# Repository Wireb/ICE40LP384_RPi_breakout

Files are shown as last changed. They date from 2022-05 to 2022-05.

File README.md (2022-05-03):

# ICE40LP384 to Raspberry Pi breakout
This repo is a collection of files related to my failed FPGA based quad scale interface board. 

The board worked but there was insufficient FPGA space for project. 

The FPGA board works and I was able to load simple projects from the Pi to the FPGA and communicate with it over SPI

## iCEcube2
The FPGA code was built with release 220.12.27943 using the free license key. See PiDRO vhdl for the source. Note this code is different than the version included in the python directory. I was not able to find the source to that version. 

## KiCad
This is a KiCad 6.x project. 

## Documentation

primary script is in the Python directory and called PiDRO.py. This loads the FPGA bitmap image to the card then communicates via the SPI bus. (The FPGA uses the SPI bus to load it's data then released the lines to internal IO control.) Note this tool uses "pigpiod" to control the Raspberry Pi's GPIOs and SPI interfaces. Make sure pigpiod is running before trying to use this script. 

There is a second script that uses GPIOzero and the SPI IO device. It worked but moved to pigpiod since it could do both SPI and GPIO in one tool. 

Either case the file you want after building the bitmap can be found in \iCEcube2\PiDRO_Implmnt\sbt\outputs\bitmap\PiDRO_bitmap.bin. The documentation was confusing and made it sound like a second tool was needed to generate the file. That is not the case just use iCEcube2 to generate the bitmap as part of the P&R steps then grab it from that directory. 

Copyright (c) 2022 Peter Shabino

Permission is hereby granted, free of charge, to any person obtaining a copy of this hardware, software, and associated documentation files 
(the "Product"), to deal in the Product without restriction, including without limitation the rights to use, copy, modify, merge, publish, 
distribute, sublicense, and/or sell copies of the Product, and to permit persons to whom the Product is furnished to do so, subject to the 
following conditions:

The above copyright notice and this permission notice shall be included in all copies or substantial portions of the Product.

THE PRODUCT IS PROVIDED "AS IS", WITHOUT WARRANTY OF ANY KIND, EXPRESS OR IMPLIED, INCLUDING BUT NOT LIMITED TO THE WARRANTIES OF 
MERCHANTABILITY, FITNESS FOR A PARTICULAR PURPOSE AND NONINFRINGEMENT. IN NO EVENT SHALL THE AUTHORS OR COPYRIGHT HOLDERS BE LIABLE 
FOR ANY CLAIM, DAMAGES OR OTHER LIABILITY, WHETHER IN AN ACTION OF CONTRACT, TORT OR OTHERWISE, ARISING FROM, OUT OF OR IN CONNECTION 
WITH THE PRODUCT OR THE USE OR OTHER DEALINGS IN THE PRODUCT.

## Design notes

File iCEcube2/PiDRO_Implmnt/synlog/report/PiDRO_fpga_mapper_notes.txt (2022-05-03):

@N: MF248 |Running in 64-bit mode.
@N: MF666 |Clock conversion enabled. (Command "set_option -fix_gated_and_generated_clocks 1" in the project file.)
@N: MO111 :|Tristate driver tri0_inst (in view: work.PiDRO(struct)) on net counts[119] (in view: work.PiDRO(struct)) has its enable tied to GND.
@N: MO111 :|Tristate driver tri1_inst (in view: work.PiDRO(struct)) on net counts[118] (in view: work.PiDRO(struct)) has its enable tied to GND.
@N: MO111 :|Tristate driver tri2_inst (in view: work.PiDRO(struct)) on net counts[117] (in view: work.PiDRO(struct)) has its enable tied to GND.
@N: MO111 :|Tristate driver tri3_inst (in view: work.PiDRO(struct)) on net counts[116] (in view: work.PiDRO(struct)) has its enable tied to GND.
@N: MO111 :|Tristate driver tri4_inst (in view: work.PiDRO(struct)) on net counts[115] (in view: work.PiDRO(struct)) has its enable tied to GND.
@N: MO111 :|Tristate driver tri5_inst (in view: work.PiDRO(struct)) on net counts[114] (in view: work.PiDRO(struct)) has its enable tied to GND.
@N: MO111 :|Tristate driver tri6_inst (in view: work.PiDRO(struct)) on net counts[113] (in view: work.PiDRO(struct)) has its enable tied to GND.
@N: MO111 :|Tristate driver tri7_inst (in view: work.PiDRO(struct)) on net counts[112] (in view: work.PiDRO(struct)) has its enable tied to GND.
@N: MO111 :|Tristate driver tri8_inst (in view: work.PiDRO(struct)) on net counts[111] (in view: work.PiDRO(struct)) has its enable tied to GND.
@N: MO111 :|Tristate driver tri9_inst (in view: work.PiDRO(struct)) on net counts[110] (in view: work.PiDRO(struct)) has its enable tied to GND.
@N: MT206 |Auto Constrain mode is enabled
@N: FX271 :"d:\cam_offload_cache\icecube2_projects\pidro\pidro\pidro.vhdl":173:1:173:3|Replicating instance SPI.shift_reg_rst (in view: work.PiDRO(struct)) with 120 loads 3 times to improve timing.
@N: FX271 :"d:\cam_offload_cache\icecube2_projects\pidro\pidro\pidro.vhdl":173:1:173:3|Replicating instance SPI.shift_reg_rst (in view: work.PiDRO(struct)) with 30 loads 2 times to improve timing.
@N: FX271 :"d:\cam_offload_cache\icecube2_projects\pidro\pidro\pidro.vhdl":173:1:173:3|Replicating instance SPI.shift_reg_rst_fast (in view: work.PiDRO(struct)) with 30 loads 2 times to improve timing.
@N: FX271 :"d:\cam_offload_cache\icecube2_projects\pidro\pidro\pidro.vhdl":173:1:173:3|Replicating instance SPI.shift_reg_rst_rep1 (in view: work.PiDRO(struct)) with 30 loads 2 times to improve timing.
@N: FX271 :"d:\cam_offload_cache\icecube2_projects\pidro\pidro\pidro.vhdl":173:1:173:3|Replicating instance SPI.shift_reg_rst_rep2 (in view: work.PiDRO(struct)) with 30 loads 2 times to improve timing.
@N: FX1016 :"d:\cam_offload_cache\icecube2_projects\pidro\pidro\pidro.vhdl":97:3:97:9|SB_GB_IO inserted on the port SPI_SCK.
@N: BW103 |The default time unit for the Synopsys Constraint File (SDC or FDC) is 1ns.
@N: BW107 |Synopsys Constraint File capacitance units using default value of 1pF 
@N: FX1056 |Writing EDF file: D:\cam_offload_cache\iCEcube2_projects\PiDRO\PiDRO\PiDRO_Implmnt\PiDRO.edf
@N: MT320 |This timing report is an estimate of place and route data. For final timing results, use the FPGA vendor place and route report.
@N: MT322 |Clock constraints include only register-to-register paths associated with each individual clock.

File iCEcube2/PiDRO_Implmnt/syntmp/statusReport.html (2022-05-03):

Project Settings
Project Name | PiDRO_syn | Implementation Name | PiDRO_Implmnt
Top Module | [auto] | Pipelining | 1
Retiming | 0 | Resource Sharing | 1
Fanout Guide | 10000 | Disable I/O Insertion | 0
Disable Sequential Optimizations | 0 | Clock Conversion | 1

Run Status
Job Name | Status | | | | CPU Time | Real Time | Memory | Date/Time
(compiler) | Complete | 24 | 3 | 0 | - | 00m:00s | - | 5/3/2022 6:25:15 PM
(premap) | Complete | 13 | 121 | 0 | 0m:00s | 0m:00s | 134MB | 5/3/2022 6:25:17 PM
(fpga_mapper) | Complete | 24 | 131 | 0 | 0m:00s | 0m:00s | 134MB | 5/3/2022 6:25:18 PM
Multi-srs Generator | Complete | | | | | | | 5/3/2022 6:25:16 PM

Area Summary
PADS | 20 | FLOPS | 133
RAMS (v_ram) | 0 | CARRYS | 0
LUTS (total_luts) | 121

Timing Summary
Clock Name | Req Freq | Est Freq | Slack
PiDRO|SPI_SCK | 249.3 MHz | 211.9 MHz | -0.708

Optimizations Summary
Combined Clock Conversion | 1 / 0

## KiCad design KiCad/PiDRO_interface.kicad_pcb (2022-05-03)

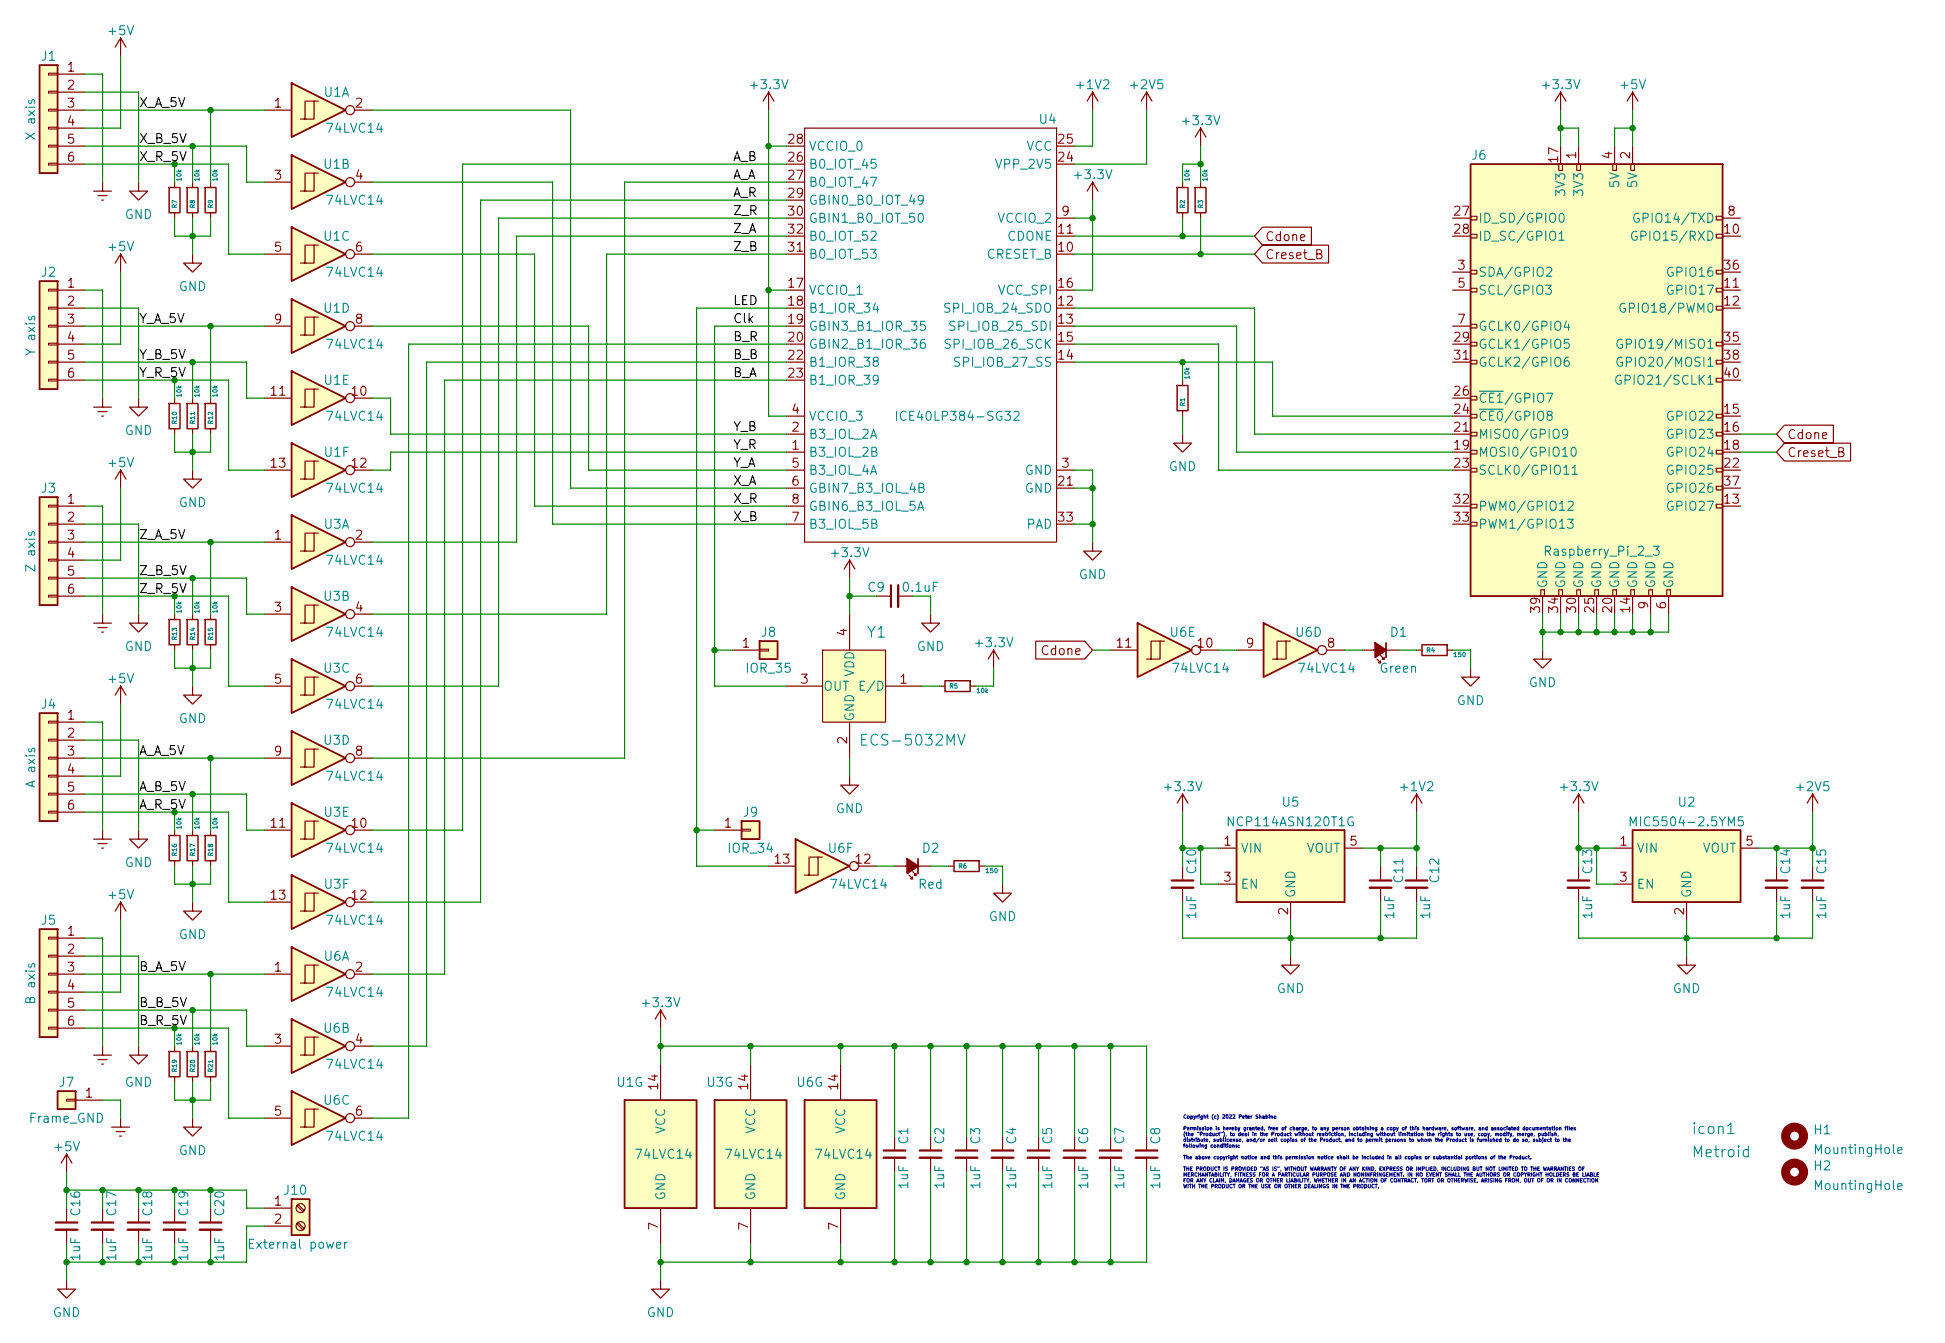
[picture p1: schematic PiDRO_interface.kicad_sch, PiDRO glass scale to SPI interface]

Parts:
C1, C2, C3, C4, C5, C6, C7, C8, C10, C11, C12, C13, C14, C15, C16, C17, C18, C19, C20: 1uF; C_0805_2012Metric
C9: 0.1uF; C_0603_1608Metric
D1: Green; LED_0805_2012Metric
D2: Red; LED_0805_2012Metric
H1, H2: MountingHole; MountingHole_2.7mm
J1: X axis; PinHeader_2x03_P2.54mm_Vertical
J2: Y axis; PinHeader_2x03_P2.54mm_Vertical
J3: Z axis; PinHeader_2x03_P2.54mm_Vertical
J4: A axis; PinHeader_2x03_P2.54mm_Vertical
J5: B axis; PinHeader_2x03_P2.54mm_Vertical
J6: Raspberry_Pi_2_3; Raspberry_Pi_Zero_Socketed_THT_FaceDown_MountingHoles
J7: Frame_GND; PinHeader_1x01_P2.54mm_Vertical
J8: IOR_35; PinHeader_1x01_P2.54mm_Vertical
J9: IOR_34; PinHeader_1x01_P2.54mm_Vertical
J10: External power; OSTTE020104
R1, R2, R3, R5, R7, R8, R9, R10, R11, R12, R13, R14, R15, R16, R17, R18, R19, R20, R21: 10k; R_0603_1608Metric
R4, R6: 150; R_0603_1608Metric
U1, U3, U6: 74LVC14; SO-14_5.3x10.2mm_P1.27mm
U2: MIC5504-2.5YM5; SOT-23-5
U4: ICE40LP384-SG32; TQFN-32-1EP_5x5mm_P0.5mm_EP2.1x2.1mm
U5: NCP114ASN120T1G; TSOP-5_1.65x3.05mm_P0.95mm
Y1: ECS-5032MV; Oscillator_XLH736022.579200I; MPN XLH736022.579200I; Digi-Key_PN 631-1277-ND
icon1: Metroid; metroid

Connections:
+1V2: C11.1, C12.1, U4.25 (VCC), U5.5 (VOUT)
+2V5: C14.1, C15.1, U2.5 (VOUT), U4.24 (VPP_2V5)
+3V3: C1.1, C2.1, C3.1, C4.1, C5.1, C6.1, C7.1, C8.1, C9.1, C10.1, C13.1, J6.1 (3V3), J6.17 (3V3), R2.1, R3.1, R5.1, U1.14 (VCC), U2.1 (VIN), U2.3 (EN), U3.14 (VCC), U4.4 (VCCIO_3), U4.9 (VCCIO_2), U4.16 (VCC_SPI), U4.17 (VCCIO_1), U4.28 (VCCIO_0), U5.1 (VIN), U5.3 (EN), U6.14 (VCC), Y1.4 (VDD)
+5V: C16.1, C17.1, C18.1, C19.1, C20.1, J1.4, J2.4, J3.4, J4.4, J5.4, J6.2 (5V), J6.4 (5V), J10.1
/A_A: U3.8, U4.27 (B0_IOT_47)
/A_B: U3.10, U4.26 (B0_IOT_45)
/A_R: U3.12, U4.29 (GBIN0_B0_IOT_49)
/B_A: U4.23 (B1_IOR_39), U6.2
/B_B: U4.22 (B1_IOR_38), U6.4
/B_R: U4.20 (GBIN2_B1_IOR_36), U6.6
/Clk: J8.1, U4.19 (GBIN3_B1_IOR_35), Y1.3 (OUT)
/LED: J9.1, U4.18 (B1_IOR_34), U6.13
/X_A: U1.2, U4.6 (GBIN7_B3_IOL_4B)
/X_B: U1.4, U4.7 (B3_IOL_5B)
/X_R: U1.6, U4.8 (GBIN6_B3_IOL_5A)
/Y_A: U1.8, U4.5 (B3_IOL_4A)
/Y_B: U1.10, U4.2 (B3_IOL_2A)
/Y_R: U1.12, U4.1 (B3_IOL_2B)
/Z_A: U3.2, U4.32 (B0_IOT_52)
/Z_B: U3.4, U4.31 (B0_IOT_53)
/Z_R: U3.6, U4.30 (GBIN1_B0_IOT_50)
Cdone: J6.16 (GPIO23), R2.2, U4.11 (CDONE), U6.11
Creset_B: J6.18 (GPIO24), R3.2, U4.10 (CRESET_B)
Earth: J1.1, J2.1, J3.1, J4.1, J5.1, J7.1
unnamed: D1.1 (K), R4.2
unnamed: D1.2 (A), U6.8
unnamed: D2.1 (K), R6.2
unnamed: D2.2 (A), U6.12
unnamed: J6.19 (MOSI0/GPIO10), U4.13 (SPI_IOB_25_SDI)
unnamed: J6.21 (MISO0/GPIO9), U4.12 (SPI_IOB_24_SDO)
unnamed: J6.23 (SCLK0/GPIO11), U4.15 (SPI_IOB_26_SCK)
unnamed: J6.24 (~CE0/GPIO8), R1.1, U4.14 (SPI_IOB_27_SS)
unnamed: R5.2, Y1.1 (E/D)
unnamed: U6.9, U6.10

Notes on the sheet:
Copyright (c) 2022 Peter Shabino Permission is hereby granted, free of charge, to any person obtaining a copy of this hardware, software, and associated documentation files (the "Product"), to deal in the Product without restriction, including without limitation the rights to use, copy, modify, mer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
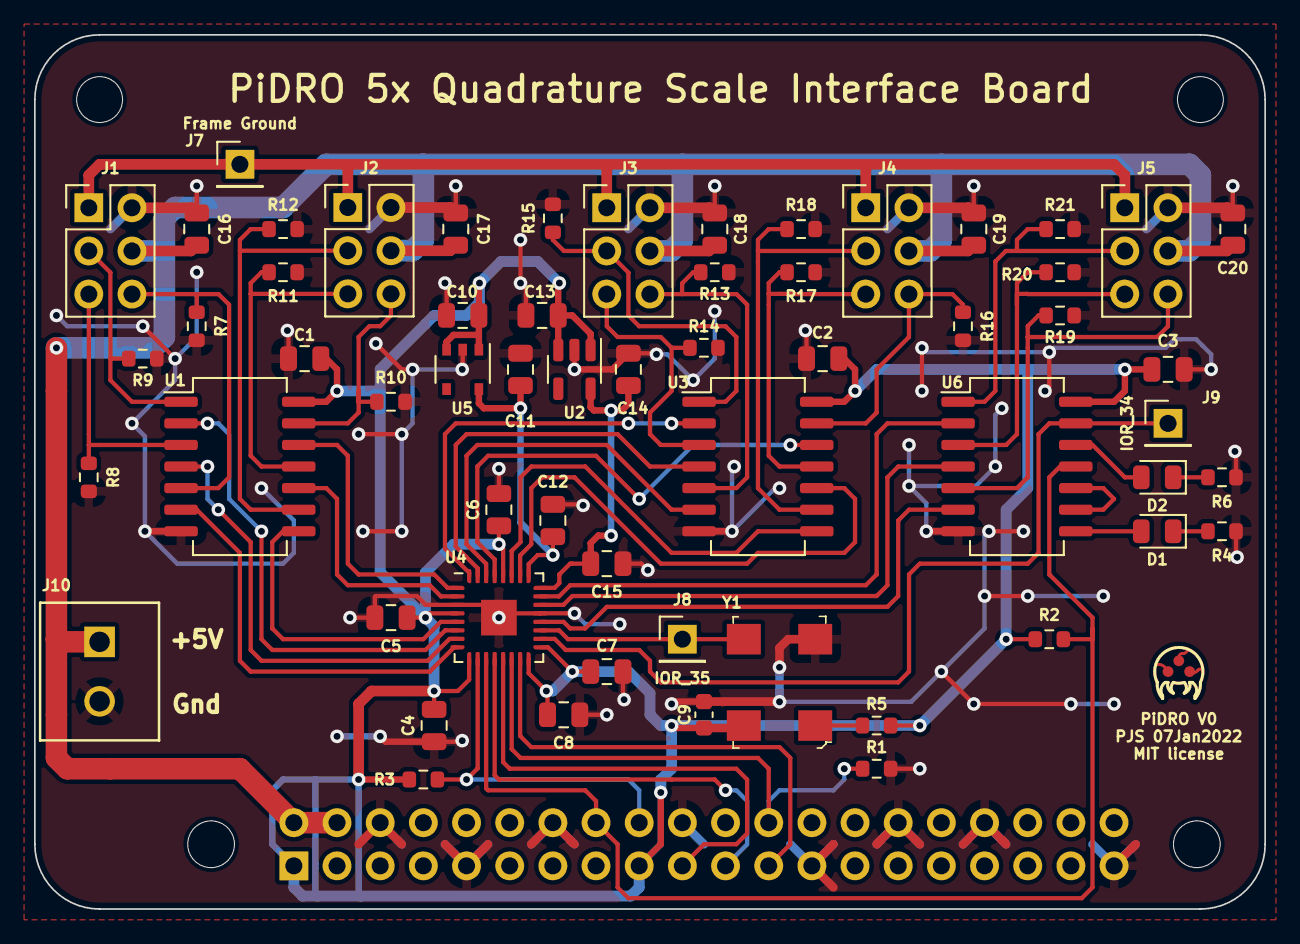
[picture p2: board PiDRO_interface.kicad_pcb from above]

Board: 2 copper layers, 72.4 x 51.4 mm, 63 parts (1 on the bottom side), 50 nets.

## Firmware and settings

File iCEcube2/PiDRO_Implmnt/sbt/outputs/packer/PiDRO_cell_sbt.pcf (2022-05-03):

ble_pack SPI.shift_reg_106_LC_2_1_1 { SPI.shift_reg_RNO[106], SPI.shift_reg[106] }
ble_pack SPI.shift_reg_105_LC_2_1_4 { SPI.shift_reg_RNO[105], SPI.shift_reg[105] }
ble_pack SPI.shift_reg_107_LC_2_1_5 { SPI.shift_reg_RNO[107], SPI.shift_reg[107] }
ble_pack SPI.shift_reg_108_LC_2_1_6 { SPI.shift_reg_RNO[108], SPI.shift_reg[108] }
ble_pack SPI.shift_reg_0_LC_2_1_7 { SPI.shift_reg_0_THRU_LUT4_0, SPI.shift_reg[0] }
clb_pack LT_2_1 { SPI.shift_reg_106_LC_2_1_1, SPI.shift_reg_105_LC_2_1_4, SPI.shift_reg_107_LC_2_1_5, SPI.shift_reg_108_LC_2_1_6, SPI.shift_reg_0_LC_2_1_7 }
set_location LT_2_1 2 1
ble_pack SPI.shift_reg_6_LC_2_2_0 { SPI.shift_reg_RNO[6], SPI.shift_reg[6] }
ble_pack SPI.shift_reg_2_LC_2_2_1 { SPI.shift_reg_RNO[2], SPI.shift_reg[2] }
ble_pack SPI.shift_reg_3_LC_2_2_2 { SPI.shift_reg_RNO[3], SPI.shift_reg[3] }
ble_pack SPI.shift_reg_4_LC_2_2_3 { SPI.shift_reg_RNO[4], SPI.shift_reg[4] }
ble_pack SPI.shift_reg_5_LC_2_2_4 { SPI.shift_reg_RNO[5], SPI.shift_reg[5] }
ble_pack SPI.shift_reg_1_LC_2_2_5 { SPI.shift_reg_RNO[1], SPI.shift_reg[1] }
ble_pack SPI.shift_reg_7_LC_2_2_6 { SPI.shift_reg_RNO[7], SPI.shift_reg[7] }
ble_pack SPI.shift_reg_8_LC_2_2_7 { SPI.shift_reg_RNO[8], SPI.shift_reg[8] }
clb_pack LT_2_2 { SPI.shift_reg_6_LC_2_2_0, SPI.shift_reg_2_LC_2_2_1, SPI.shift_reg_3_LC_2_2_2, SPI.shift_reg_4_LC_2_2_3, SPI.shift_reg_5_LC_2_2_4, SPI.shift_reg_1_LC_2_2_5, SPI.shift_reg_7_LC_2_2_6, SPI.shift_reg_8_LC_2_2_7 }
set_location LT_2_2 2 2
ble_pack SPI.shift_reg_10_LC_2_3_0 { SPI.shift_reg_RNO[10], SPI.shift_reg[10] }
ble_pack SPI.shift_reg_9_LC_2_3_1 { SPI.shift_reg_RNO[9], SPI.shift_reg[9] }
ble_pack SPI.shift_reg_11_LC_2_3_2 { SPI.shift_reg_RNO[11], SPI.shift_reg[11] }
ble_pack SPI.shift_reg_12_LC_2_3_3 { SPI.shift_reg_RNO[12], SPI.shift_reg[12] }
ble_pack SPI.shift_reg_13_LC_2_3_4 { SPI.shift_reg_RNO[13], SPI.shift_reg[13] }
ble_pack SPI.shift_reg_14_LC_2_3_5 { SPI.shift_reg_RNO[14], SPI.shift_reg[14] }
ble_pack SPI.shift_reg_15_LC_2_3_6 { SPI.shift_reg_RNO[15], SPI.shift_reg[15] }
ble_pack SPI.shift_reg_16_LC_2_3_7 { SPI.shift_reg_RNO[16], SPI.shift_reg[16] }
clb_pack LT_2_3 { SPI.shift_reg_10_LC_2_3_0, SPI.shift_reg_9_LC_2_3_1, SPI.shift_reg_11_LC_2_3_2, SPI.shift_reg_12_LC_2_3_3, SPI.shift_reg_13_LC_2_3_4, SPI.shift_reg_14_LC_2_3_5, SPI.shift_reg_15_LC_2_3_6, SPI.shift_reg_16_LC_2_3_7 }
set_location LT_2_3 2 3
ble_pack SPI.shift_reg_rst_fast_rep1_LC_3_1_4 { SPI.shift_reg_rst_fast_rep1_THRU_LUT4_0, SPI.shift_reg_rst_fast_rep1 }
clb_pack LT_3_1 { SPI.shift_reg_rst_fast_rep1_LC_3_1_4 }
set_location LT_3_1 3 1
ble_pack SPI.shift_reg_109_LC_3_2_0 { SPI.shift_reg_RNO[109], SPI.shift_reg[109] }
ble_pack SPI.shift_reg_110_LC_3_2_1 { SPI.shift_reg_RNO[110], SPI.shift_reg[110] }
ble_pack SPI.shift_reg_111_LC_3_2_2 { SPI.shift_reg_RNO[111], SPI.shift_reg[111] }
ble_pack SPI.shift_reg_112_LC_3_2_3 { SPI.shift_reg_RNO[112], SPI.shift_reg[112] }
ble_pack SPI.shift_reg_113_LC_3_2_4 { SPI.shift_reg_RNO[113], SPI.shift_reg[113] }
ble_pack SPI.shift_reg_114_LC_3_2_5 { SPI.shift_reg_RNO[114], SPI.shift_reg[114] }
ble_pack SPI.shift_reg_115_LC_3_2_6 { SPI.shift_reg_RNO[115], SPI.shift_reg[115] }
ble_pack SPI.shift_reg_116_LC_3_2_7 { SPI.shift_reg_RNO[116], SPI.shift_reg[116] }
clb_pack LT_3_2 { SPI.shift_reg_109_LC_3_2_0, SPI.shift_reg_110_LC_3_2_1, SPI.shift_reg_111_LC_3_2_2, SPI.shift_reg_112_LC_3_2_3, SPI.shift_reg_113_LC_3_2_4, SPI.shift_reg_114_LC_3_2_5, SPI.shift_reg_115_LC_3_2_6, SPI.shift_reg_116_LC_3_2_7 }
set_location LT_3_2 3 2
ble_pack SPI.shift_reg_rst_LC_3_3_0 { SPI.shift_reg_rst_THRU_LUT4_0, SPI.shift_reg_rst }
ble_pack SPI.shift_reg_rst_fast_0_LC_3_3_2 { SPI.shift_reg_rst_fast_0_THRU_LUT4_0, SPI.shift_reg_rst_fast_0 }
ble_pack SPI.shift_reg_rst_fast_fast_LC_3_3_3 { SPI.shift_reg_rst_fast_fast_THRU_LUT4_0, SPI.shift_reg_rst_fast_fast }
ble_pack SPI.shift_reg_rst_rep1_LC_3_3_5 { SPI.shift_reg_rst_rep1_THRU_LUT4_0, SPI.shift_reg_rst_rep1 }
ble_pack SPI.shift_reg_rst_rep1_0_LC_3_3_6 { SPI.shift_reg_rst_rep1_0_THRU_LUT4_0, SPI.shift_reg_rst_rep1_0 }
ble_pack SPI.shift_reg_rst_rep1_fast_LC_3_3_7 { SPI.shift_reg_rst_rep1_fast_THRU_LUT4_0, SPI.shift_reg_rst_rep1_fast }
clb_pack LT_3_3 { SPI.shift_reg_rst_LC_3_3_0, SPI.shift_reg_rst_fast_0_LC_3_3_2, SPI.shift_reg_rst_fast_fast_LC_3_3_3, SPI.shift_reg_rst_rep1_LC_3_3_5, SPI.shift_reg_rst_rep1_0_LC_3_3_6, SPI.shift_reg_rst_rep1_fast_LC_3_3_7 }
set_location LT_3_3 3 3
ble_pack SPI.shift_reg_22_LC_3_4_0 { SPI.shift_reg_RNO[22], SPI.shift_reg[22] }
ble_pack SPI.shift_reg_23_LC_3_4_1 { SPI.shift_reg_RNO[23], SPI.shift_reg[23] }
ble_pack SPI.shift_reg_24_LC_3_4_2 { SPI.shift_reg_RNO[24], SPI.shift_reg[24] }
ble_pack SPI.shift_reg_25_LC_3_4_3 { SPI.shift_reg_RNO[25], SPI.shift_reg[25] }
ble_pack SPI.shift_reg_26_LC_3_4_4 { SPI.shift_reg_RNO[26], SPI.shift_reg[26] }
ble_pack SPI.shift_reg_27_LC_3_4_5 { SPI.shift_reg_RNO[27], SPI.shift_reg[27] }
ble_pack SPI.shift_reg_28_LC_3_4_6 { SPI.shift_reg_RNO[28], SPI.shift_reg[28] }
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

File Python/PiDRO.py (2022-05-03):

# IO map
# GPIO8 - SPI SS - pull down
# GPIO9 - SPI MISO0
# GPIO10 - SPI MOSI0
# GPIO11 - SCLK0
# GPIO23 - Cdone - pull up - green LED when high
# GPIO24 - Creset_B - pull up 

# start pigpio with "sudo pigpiod"
# automatic startup "sudo systemctl enable pigpiod"
# https://scispec.dev/2020/04/04/blink-led-with-python-and-pigpio-library-2/
# pigpio documentation https://abyz.me.uk/rpi/pigpio/python.html
# https://www.dummies.com/article/technology/computers/hardware/raspberry-pi/raspberry-pi-gpio-pin-alternate-functions-143761



import time
import sys
import pigpio 

###############################################
bitmap_file = "./PiDRO_bitmap.bin"
# pins
SPI_SS = 8
SPI_MISO = 9
SPI_MOSI = 10
SPI_CLK = 11
Cdone = 23
Creset_B = 24



###############################################
# open GPIO pins
pi = pigpio.pi()

# setup GPIOs
pi.set_mode(SPI_SS, pigpio.OUTPUT)
pi.set_mode(Cdone, pigpio.INPUT)
pi.set_mode(Creset_B, pigpio.OUTPUT)

# setup SPI
# SPI engine 0 is on ALT0 pins
#pi.set_mode(SPI_SS, pigpio.ALT0)  # set to manual control for now. 
pi.set_mode(SPI_MISO, pigpio.ALT0)
pi.set_mode(SPI_MOSI, pigpio.ALT0)
pi.set_mode(SPI_CLK, pigpio.ALT0)
spi = pi.spi_open(spi_channel=0, baud=2000000, spi_flags=0x000003)
# SPI flags 
#21 20 19 18 17 16  |  15 14 13 12 11 10  9  8  |  7  6  5  4  3  2  1  0
# b  b  b  b  b  b  |  R  T  n  n  n  n   W  A  |  u2 u1 u0 p2 p1 p0  m  m
# b = word size set to 0 for 8 bit (default). Aux SPI only
# R = 1 LSB received first, 0 = MSB received first (default) Aux SPI only
# T = 1 LSB sent first, 0 = MSB sent first (default) Aux SPI only
# n = number of bytes to write before switching to read. Ingored if W not set
# W = 1 3 wire mode, 0 = 4 wire mode (default). Main SPI only
# A = 1 for Aux SPI engine, 0 = main engine (default)
# ux = 0 if pin is reserved for SPI (default) 
# px = 0 for active low, 1 for active high (does this even work still due to kernel change?)
# m = SPI mode bits POL(clk), PHA(data latch) note modes 1 and 3 do not seem to work on Aux SPI engine.

#init FPGA
print("reset FPGA")
# drive Creset_B low to reset FPGA
pi.write(Creset_B, False)
# drive SPI_SS low 
pi.write(SPI_SS, False)
# hold reset for at least 200nS
time.sleep(1/1000000)  # 1uS

# check if FPGA is reset
if(pi.read(Cdone) == 1):
    print("Error occurred Cdone is active. Exiting")
    sys.exit(-1)

# release reset
pi.write(Creset_B, True)
# allow at least 1200us for the iCE40 to clear internal memory
time.sleep(2000/1000000)  # 2000uS

print("Load FPGA image")
# drive SPI_SS high for 8 SPI clock cycles
pi.write(SPI_SS, True)
pi.spi_write(spi, [0x00])
# read in bitmap
print("  file "+bitmap_file)
file = open(bitmap_file, mode='rb')
bitmap_data = file.read()
file.close()
print("  Read "+str(len(bitmap_data))+" bitmap bytes")
# drive SS active (low)
pi.write(SPI_SS, False)
# send full bitmap
pi.spi_write(spi, bitmap_data)
# drive SS inactive (high)
pi.write(SPI_SS, True)

# send 100 more bytes
for x in range(100):
    pi.spi_write(spi, [0x00])


if(pi.read(Cdone) == 0):
    print("Error occurred Cdone is inactive. Exiting")
    sys.exit(-1)


# drive SS active (low)
pi.write(SPI_SS, False)
# read 15 bytes
(b, d) = pi.spi_xfer(spi, [0xB0, 0xB0, 0xC0, 0xED, 0, 0, 0, 0, 0, 0, 0, 0, 0, 0, 0])
# drive SS inactive (high)
pi.write(SPI_SS, True)

print("xfer 2 got ",b," bytes")
print(d)

while(1):
    # drive SS active (low)
    pi.write(SPI_SS, False)
    # read 15 bytes
    (b, d) = pi.spi_xfer(spi, [1, 2, 3, 4, 0, 0, 0, 0, 0, 0, 0, 0, 0xFF, 0xFF, 0xFF])
    # drive SS inactive (high)
    pi.write(SPI_SS, True)

    print("got ",b," bytes")
    print(d)
    
    time.sleep(1)

print("script done")
sys.exit()

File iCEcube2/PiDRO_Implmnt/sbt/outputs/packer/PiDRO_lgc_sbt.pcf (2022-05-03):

set_location CONSTANT_ONE_LUT4 5 6 7 #SB_LUT4
set_location SPI.shift_reg_rst_rep2_rep1_THRU_LUT4_0 4 6 3 #SB_LUT4
set_location SPI.shift_reg_rst_rep2_fast_THRU_LUT4_0 4 6 2 #SB_LUT4
set_location SPI.shift_reg_rst_rep2_THRU_LUT4_0 4 6 1 #SB_LUT4
set_location SPI.shift_reg_rst_rep1_rep1_THRU_LUT4_0 4 6 0 #SB_LUT4
set_location SPI.shift_reg_rst_rep1_fast_THRU_LUT4_0 3 3 7 #SB_LUT4
set_location SPI.shift_reg_rst_rep1_0_THRU_LUT4_0 3 3 6 #SB_LUT4
set_location SPI.shift_reg_rst_rep1_THRU_LUT4_0 3 3 5 #SB_LUT4
set_location SPI.shift_reg_rst_fast_rep1_THRU_LUT4_0 3 1 4 #SB_LUT4
set_location SPI.shift_reg_rst_fast_fast_THRU_LUT4_0 3 3 3 #SB_LUT4
set_location SPI.shift_reg_rst_fast_0_THRU_LUT4_0 3 3 2 #SB_LUT4
set_location SPI.shift_reg_rst_fast_THRU_LUT4_0 5 2 6 #SB_LUT4
set_location SPI.shift_reg_rst_THRU_LUT4_0 3 3 0 #SB_LUT4
set_location SPI.shift_reg_0_THRU_LUT4_0 2 1 7 #SB_LUT4
set_location SPI.shift_reg_RNO[44] 4 7 6 #SB_LUT4
set_location SPI.shift_reg_RNO[23] 3 4 1 #SB_LUT4
set_location SPI.shift_reg_RNO[96] 5 1 4 #SB_LUT4
set_location SPI.shift_reg_RNO[5] 2 2 4 #SB_LUT4
set_location SPI.shift_reg_rst_rep2_rep1 4 6 3 #SB_DFFNR
set_location SPI.shift_reg_rst_fast 5 2 6 #SB_DFFNR
set_location SPI.shift_reg_RNO[103] 4 1 4 #SB_LUT4
set_location SPI.shift_reg[90] 4 2 4 #SB_DFFN
set_location SPI.shift_reg[26] 3 4 4 #SB_DFFN
set_location SPI.shift_reg[113] 3 2 4 #SB_DFFN
set_location SPI.shift_reg[0] 2 1 7 #SB_DFFN
set_location SPI.shift_reg_RNO[41] 3 7 3 #SB_LUT4
set_location SPI.shift_reg_RNO[28] 3 4 6 #SB_LUT4
set_location SPI.shift_reg[45] 4 7 7 #SB_DFFN
set_location SPI.shift_reg_rst_fast_0 3 3 2 #SB_DFFNR
set_location SPI.shift_reg_RNO[19] 4 3 5 #SB_LUT4
set_location SPI.shift_reg[67] 4 3 7 #SB_DFFN
set_location SPI.shift_reg_RNO[59] 3 5 5 #SB_LUT4
set_location SPI.shift_reg_RNO[112] 3 2 3 #SB_LUT4
set_location SPI.shift_reg_RNO[106] 2 1 1 #SB_LUT4
set_location SPI.shift_reg[5] 2 2 4 #SB_DFFN
set_location SPI.shift_reg[118] 4 2 1 #SB_DFFN
set_location SPI.shift_reg_RNO[80] 4 5 7 #SB_LUT4
set_location SPI.shift_reg_RNO[8] 2 2 7 #SB_LUT4
set_location SPI.shift_reg_RNO[67] 4 3 7 #SB_LUT4
set_location SPI.shift_reg_RNO[32] 3 6 2 #SB_LUT4
set_location SPI.shift_reg[42] 3 7 4 #SB_DFFN
set_location SPI.shift_reg_RNO[98] 5 1 2 #SB_LUT4
set_location SPI.shift_reg_RNO[14] 2 3 5 #SB_LUT4
set_location SPI.shift_reg[82] 4 5 4 #SB_DFFN
set_location SPI.shift_reg[60] 3 5 1 #SB_DFFN
set_location SPI.shift_reg[37] 3 6 7 #SB_DFFN
set_location SPI.shift_reg[18] 4 3 4 #SB_DFFN
set_location SPI.shift_reg[102] 4 1 3 #SB_DFFN
set_location SPI.shift_reg_RNO[85] 4 4 2 #SB_LUT4
set_location SPI.shift_reg_RNO[35] 3 6 0 #SB_LUT4
set_location SPI.shift_reg[71] 4 5 0 #SB_DFFN
set_location SPI.SDO_RNO 5 3 6 #SB_LUT4
set_location SPI.shift_reg_RNO[13] 2 3 4 #SB_LUT4
set_location SPI.shift_reg[87] 4 2 5 #SB_DFFN
set_location SPI.shift_reg[32] 3 6 2 #SB_DFFN
set_location SPI.shift_reg[13] 2 3 4 #SB_DFFN
set_location SPI.shift_reg_RNO[76] 5 5 6 #SB_LUT4
set_location SPI.shift_reg_RNO[53] 3 7 7 #SB_LUT4
set_location SPI.shift_reg_RNO[20] 4 3 6 #SB_LUT4
set_location SPI.shift_reg_RNO[118] 4 2 1 #SB_LUT4
set_location SPI.shift_reg[53] 3 7 7 #SB_DFFN
set_location SPI.shift_reg[105] 2 1 4 #SB_DFFN
set_location SPI.shift_reg_RNO[95] 5 1 6 #SB_LUT4
set_location SPI.shift_reg_RNO[38] 3 7 0 #SB_LUT4
set_location SPI.shift_reg_RNO[2] 2 2 1 #SB_LUT4
set_location SPI.shift_reg[74] 5 5 4 #SB_DFFN
set_location SPI.shift_reg[93] 4 1 7 #SB_DFFN
set_location SPI.shift_reg[39] 3 7 1 #SB_DFFN
set_location SPI.shift_reg[23] 3 4 1 #SB_DFFN
set_location SPI.shift_reg[16] 2 3 7 #SB_DFFN
set_location SPI.shift_reg[110] 3 2 1 #SB_DFFN
set_location SPI.shift_reg_RNO[71] 4 5 0 #SB_LUT4
set_location SPI.shift_reg_RNO[56] 3 5 0 #SB_LUT4
set_location SPI.shift_reg_RNO[42] 3 7 4 #SB_LUT4
set_location SPI.shift_reg_RNO[25] 3 4 3 #SB_LUT4
set_location SPI.shift_reg[108] 2 1 6 #SB_DFFN
set_location SPI.shift_reg_RNO[90] 4 2 4 #SB_LUT4
set_location SPI.shift_reg_RNO[7] 2 2 6 #SB_LUT4
set_location SPI.shift_reg[68] 4 3 1 #SB_DFFN
set_location SPI.shift_reg_RNO[117] 4 2 0 #SB_LUT4
set_location SPI.shift_reg_RNO[105] 2 1 4 #SB_LUT4
set_location SPI.shift_reg[96] 5 1 4 #SB_DFFN
set_location SPI.shift_reg[6] 2 2 0 #SB_DFFN
set_location SPI.shift_reg[24] 3 4 2 #SB_DFFN
set_location SPI.shift_reg[115] 3 2 6 #SB_DFFN
set_location SPI.shift_reg_RNO[64] 4 4 1 #SB_LUT4
set_location SPI.shift_reg[59] 3 5 5 #SB_DFFN
set_location SPI.shift_reg[47] 4 7 1 #SB_DFFN
set_location SPI.shift_reg[65] 4 4 3 #SB_DFFN
set_location SPI.shift_reg_rst 3 3 0 #SB_DFFNR
set_location SPI.shift_reg_RNO[110] 3 2 1 #SB_LUT4
set_location SPI.shift_reg[99] 5 1 0 #SB_DFFN
set_location SPI.shift_reg[29] 3 5 7 #SB_DFFN
set_location SPI.shift_reg_rst_fast_fast 3 3 3 #SB_DFFNR
set_location SPI.shift_reg_RNO[86] 4 3 0 #SB_LUT4
set_location SPI.shift_reg_RNO[61] 4 4 6 #SB_LUT4
set_location SPI.shift_reg_RNO[48] 4 7 2 #SB_LUT4
set_location SPI.shift_reg_RNO[30] 3 5 6 #SB_LUT4
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

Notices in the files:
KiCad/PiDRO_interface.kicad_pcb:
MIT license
